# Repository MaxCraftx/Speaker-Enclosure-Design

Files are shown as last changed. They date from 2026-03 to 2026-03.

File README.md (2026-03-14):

# Speaker Enclosure Design

Custom lightweight speaker enclosures for a curved zero-gravity workstation. 

This repository serves as the engineering workspace for redesigning **Bose FreeSpace DS 100F** donor acoustic components into custom, overhead-mounted housings.

## Donor Baseline
The core donor is the **Bose DS 100F**:
- 5.25" woofer + 2.25" Twiddler® driver
- Ported acoustic architecture
- 160° conical coverage (ideal for near-field overhead mounting)

*Note: This project was originally conceptualized around the Bose DesignMax DM8C. All legacy DM8C assumptions (sealed 21.8L volume, 8" coaxial) have been superseded by the DS 100F rebaseline.*

## Current Status
- **Scans completed:** Front panel/base, backcan, connector panel, and bass reflex vent have been captured (Creality Scan 4.7, CR-Scan Raptor).
- **Engineering OS:** Documentation and reverse engineering are actively moving into Fusion 360.
- **Next Steps:** Datum extraction, port geometry measurement, and master assembly creation.

## Repository Structure
- `docs/01_project_rebaseline/`: Reports on the DM8C to DS 100F transition
- `docs/02_donor_ds100f/`: Extracted dimensional and acoustic registers for the new donor
- `docs/03_scans/`: Inventory and processing workflow for 3D scan data
- `docs/04_cad_workflow/`: Fusion 360 conventions and parameter schemas
- `docs/05_validation/`: Measurement and testing plans
- `DESIGN_PROPOSAL.md`: The core design concepts and architecture

## Usage
This repo establishes a strict scan-driven CAD workflow. Please see `docs/04_cad_workflow/FUSION_WORKFLOW.md` before contributing CAD data, and review `PROJECT_BACKLOG.md` for current priorities.

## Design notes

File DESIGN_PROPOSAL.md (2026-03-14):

# Custom Lightweight Speaker Enclosures for Curved Zero-Gravity Workstation

**Redesign of Bose FreeSpace DS 100F donor acoustic components into futuristic, vacuum-formed workstation-integrated stereo housings**

---

<table>
<tr>
<td width="55%" valign="top">

## 1 · Executive Summary

This proposal describes the redesign of a stereo pair of loudspeaker enclosures using donor acoustic components from the **Bose FreeSpace DS 100F** ceiling loudspeaker. The new enclosures are purpose-built for overhead mounting on the motorised monitor arm of a curved zero-gravity workstation.

**Core objectives:**

- Replace the current provisional white speakers with custom-designed stereo housings that integrate visually and mechanically with the workstation architecture
- Preserve the acoustic performance of the donor Bose system — internal volume, ported architecture, crossover behaviour, and baffle conditions
- Achieve significant weight reduction through vacuum-formed **HIPS** (High Impact Polystyrene) shells with targeted internal reinforcement
- Present eight design variants ranging from smooth biomorphic to structurally-integrated nacelle forms, all sharing a **rounded wedge profile** with a **kidney-shaped plan footprint**

**Key constraints:** ≤ 25 kg total arm payload (including three monitors), donor acoustic volume (TBD pending scan extraction), Formech 300XQ vacuum former forming envelope (430 × 280 mm).

</td>
<td width="45%" valign="top">

<!-- IMAGE: hero_workstation.png -->
Workstation context — speakers mounted on monitor arm

*Concept rendering: custom speaker enclosures integrated into the curved monitor structure*

</td>
</tr>
</table>

---

<table>
<tr>
<td width="55%" valign="top">

## 2 · Background and Need

The workstation uses a multi-monitor overhead structure with pronounced curvature and limited spare load capacity on its motorised arm system. The currently mounted white speakers are functionally provisional and do not match the visual language, curvature, or packaging logic of the station.

**Four justifications for redesign:**

| Driver | Rationale |
|---|---|
| **Aesthetic integration** | The current loudspeakers visually interrupt an otherwise cohesive, futuristic workstation form |
| **Geometric compatibility** | A custom kidney-shaped wedge can follow the monitor arc and reduce visual bulk |
| **Mass reduction** | The new housings must be lighter than the 5.9 kg donor enclosure — the arm has ≤ 25 kg total capacity including monitors |
| **Performance retention** | Tonal balance, dispersion, and output capability of the donor transducers and crossover must be preserved |

The Bose DS 100F is selected as the donor platform because it provides an exceptionally wide 160° conical coverage from a dual-driver array — ideal for near-field overhead listening in an unconventional mounting position where the operator's head position may shift.

</td>
<td width="45%" valign="top">

<!-- IMAGE: current workstation photo showing provisional speakers -->
Current workstation with provisional speakers

*Reference: current provisional white speakers on the monitor arm (to be replaced)*

</td>
</tr>
</table>

---

## 3 · Donor System Reference

### Bose FreeSpace DS 100F — Core Baseline
*See `docs/02_donor_ds100f` for complete, verified specifications.*

| Parameter | Value | Near-field relevance |
|---|---|---|
| **Low-frequency driver** | 5.25-inch (133 mm) woofer | Deep enough for near-field without a sub |
| **High-frequency driver** | 2.25-inch (57 mm) Twiddler® | Wide frequency band handler |
| **Frequency Response** | 75 Hz – 18 kHz (±3 dB) | Full voice and music coverage |
| **Enclosure Type** | Ported | Must extract port geometry from scans |
| **Nominal coverage** | 160° conical | **Critical advantage:** extreme off-axis tolerance |
| **Unit weight (complete)**| 5.9 kg | Substantially lighter than prior DM8C donor |

> [!TIP]
> **Key insight for this project:** The DS 100F's greatest asset for near-field overhead use is its **160° conical dispersion**. The operator is reclined and off-axis; the extreme dispersion means usable response even at large angles. Normal studio monitors offer only 60–90°, requiring strict mechanical aiming.

### Donor Internal Volume Calculation (TBD)
The exact internal acoustic core volume must be extracted from the 3D scans of the DS 100F backcan using CloudCompare (`ac_vol_target`). The gross external volume of the new enclosure will be larger once shell thickness, ribs, and mounting structure are added.

### Components to Transfer from Donor

| Component | Transfer | Notes |
|---|:---:|---|
| 5.25" woofer + 2.25" Twiddler | **Yes** | Core acoustic element — mounted on new baffle |
| Passive crossover PCB | **Yes** | Preserves factory voicing — mount with vibration isolation |
| 70/100 V transformer | **Remove** | Not needed for direct 8 Ω connection (weight TBD) |
| Bass reflex port geometry | **Yes** | Replicate exactly via dimension extraction (TBD) |
| Cast/plastic backcan | **Discard** | Replaced by custom HIPS shell |

---

<table>
<tr>
<td width="55%" valign="top">

## 4 · Design Language

### Form Vocabulary

The enclosure form language is driven by integration with the workstation's visual identity:

- **Rounded wedge profile** — deeper at the rear, tapering toward the listener
- **Kidney-shaped footprint** — asymmetric plan view following the monitor arc radius
- **Flowing surfaces** — continuous curvature with no sharp creases, compatible with vacuum forming draft requirements
- **Matte black HIPS** — non-reflective, tactile surface finish consistent with professional equipment
- **Subtle seam lines** — thermoforming split lines treated as deliberate trim details, not hidden joints
- **Integrated mount** — compact engineered bracket that reads as part of the enclosure, not an afterthought

</td>
<td width="45%" valign="top">

<!-- IMAGE: design language mood board or form studies -->
Design language reference

*Form vocabulary: rounded wedge × kidney footprint × monitor arc curvature*

</td>
</tr>
</table>

---

## 5 · Design Variants

Eight variants explore the design space from organic to structural within the shared form vocabulary. All variants share the same acoustic core, ported loading, passive crossover, and mounting interface.

### Overview of Concept Directions
1. **Variant A: Smooth Biomorphic Wedge** - Continuous curvature, minimal seam lines.
2. **Variant B: Technical Faceted Wedge** - Facets stiffen the shell geometrically.
3. **Variant C: Aggressive Aerodynamic Wedge** - Forward-leaning stance with ridge lines.
4. **Variant D: Arc-Matched Curvature** - Maximum architectural integration.
5. **Variant E: Manta Ray** - Ultra-flat, wide-span profile to minimize visual height.
6. **Variant F: Split Clamshell** - Prominent equator split becomes a deliberate design feature.
7. **Variant G: Cantilevered Blade** - Speaker thrusts forward from a structural rib.
8. **Variant H: Wraparound Nacelle** - Enclosure wraps the arm tube structurally.

> [!TIP]
> **Shortlist recommendation:** Variants **B** (faceted self-stiffening), **C** (best driver aim), and **F** (easiest to build and service) represent the strongest candidates for first CAD prototyping.

---

<table>
<tr>
<td width="55%" valign="top">

## 6 · Acoustic Strategy for Near-Field Overhead Use

The goal is to **preserve** the DS 100F's voicing while optimising the enclosure for overhead near-field listening at ≈0.8–1.5 m distance.

### Acoustic Path & Volume Preservation
The DS 100F is explicitly a **ported** enclosure. To ensure the best fidelity, the new enclosure must:
1. Hit the target internal volume (`ac_vol_target`) extracted from scans.
2. Meticulously replicate the original port geometry (inner diameter flare and length — TBD).
3. Ensure all shell joints are sealed (gaskets at split lines) to prevent air leaks that would detune the port.

### Driver Orientation — Near-Field Aim
The dual-driver array will be mounted on an angled internal baffle aimed downward-forward toward the operator's head position. Target aim angle: **15–25° below horizontal**, confirmed by CAD study. Thanks to the 160° coverage, precise aiming is less critical than with conventional monitors.

### Baffle Diffraction
The original circular grille provides consistent edge diffraction. The new kidney-shaped front aperture creates asymmetric diffraction. Mitigation includes rounded baffle edges (minimum 10 mm radius) and felt diffraction rings if required following acoustic testing.

</td>
<td width="45%" valign="top">

<!-- IMAGE: cross_section.png -->
Internal cross-section

*Cross-section: driver array on angled baffle, matched port, crossover relocation*

</td>
</tr>
</table>

---

<table>
<tr>
<td width="55%" valign="top">

## 7 · Mounting and Integration

### Arm Load Budget

| Component | Est. Weight |
|---|:-:|
| Three monitors | ~15–18 kg |
| Monitor brackets & cabling | ~2 kg |
| **Budget remaining for speakers** | **~5–8 kg** |
| Target per speaker | **≤ 4.5 kg** |

The DS 100F complete donor weighs 5.9 kg. Removing the heavy backcan housing and the 70V transformer will drop this core weight significantly (exact savings TBD via teardown). The multi-layer HIPS shell and bracket will add 0.8–1.5 kg. The ≥ 4.5 kg target is comfortably achievable with this donor.

</td>
<td width="45%" valign="top">

<!-- IMAGE: mounting_detail.png -->
Mounting bracket detail

*Mounting concept: clamp bracket with vibration isolation and adjustment*

</td>
</tr>
</table>

---

## 8 · Materials and Manufacturing

### Primary Material: HIPS (High Impact Polystyrene)
Target > 6 mm thickness (multi-layer laminate) to ensure acoustic rigidity. Internal bonded ribs will supplement shell stiffness to prevent oil-canning.

### Formech 300XQ Constraints
Max forming area: 430 × 280 mm. The shell must be produced as a **multi-part assembly** because the kidney footprint will exceed these limits.
- Upper shell (top + sides)
- Lower shell / baffle panel
- Internal structural baffle (CNC-cut MDF or PU)
- M5 threaded mounting inserts

### Assembly Sequence
1. Vacuum-form shells.
2. CNC-trim outline and apertures.
3. Bond stiffening ribs and mounting inserts.
4. Install baffle with driver array and ported tube.
5. Apply acoustic damping and join shells.

---

## 9 · Verification and Backlog
Please refer to `PROJECT_BACKLOG.md` for macro project phases and ownership.
Validation testing is defined in `docs/05_validation/VALIDATION_PLAN.md`.
All unknown physical dimensions required to commence CAD modeling are tracked in `docs/05_validation/ASSUMPTIONS_AND_TBD.md`.

---

*Document: PQ-SPEAKER-ENC-PROPOSAL-v3.0*
*Project: Phantom Quantum — Zero-Gravity Workstation Speaker Integration*
*Donor Baseline: Bose FreeSpace DS 100F*

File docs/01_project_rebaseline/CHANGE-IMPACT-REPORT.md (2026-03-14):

# Change Impact Report: DM8C to DS 100F Rebaseline

## 1. Donor Change Summary

The project was originally structured around repurposing the Bose DesignMax DM8C. It has been formally rebaselined to use the **Bose FreeSpace DS 100F**. 
All documentation, CAD intent, and validation plans must reflect this change.

## 2. Acoustic Architecture Impact
- **Prior intent (DM8C):** 8-inch coaxial point source, treated as sealed internal volume (or unknown).
- **New intent (DS 100F):** 5.25-inch woofer and 2.25-inch Twiddler® driver array. Explicitly **ported** architecture.
- **Consequence:** The internal volume target and bass reflex vent dimensions must now be extracted from the scans of the DS 100F backcan and preserved in the new enclosure.

## 3. Geometry Impact
- **Prior intent (DM8C):** 21.8 L internal volume, large 409 mm grille diameter, ~340 mm backcan.
- **New intent (DS 100F):** The DS 100F is significantly more compact (299 mm outer flange, 193 mm depth).
- **Consequence:** The required internal acoustic volume is substantially smaller (exact value TBD pending scan extraction). The physical size of the final custom enclosure will be reduced, improving workstation packaging and sightlines.

## 4. Mass Budget Impact
- **Prior intent (DM8C):** Donor total weight 9.6 kg.
- **New intent (DS 100F):** Donor total weight 5.9 kg.
- **Consequence:** The project enjoys a much more forgiving mass budget. The target weight of ≤ 4.5 kg per enclosure remains, but it is much easier to achieve given the lighter donor.

## 5. Design Language Implications
- The 160° conical coverage of the DS 100F is even wider than the DM8C's 135°. This further reduces the criticality of precise angular alignment toward the operator.
- The dual-driver arrangement (woofer + Twiddler) introduces a new baffle face constraint compared to the single coaxial driver.

## 6. Manufacturing Implications
- Lighter donor components mean internal mounting bosses and baffle structures do not need to be as robust as previously envisioned. Vacuum-formed HIPS remains the primary shell strategy.

## 7. Validation Implications
- The acoustic validation baseline shifts to 75 Hz – 18 kHz (±3 dB).
- Port tuning frequency must be explicitly verified against the donor behavior.

## 8. Explicit List of Legacy Assumptions to Delete
The following assumptions from the concept phase are **superseded and invalid**:
1. "The enclosure requires 21.8 litres of internal volume."
2. "The donor is an 8-inch coaxial driver."
3. "The acoustic loading type is unknown/sealed."
4. "The donor weighs 9.6 kg."
5. "Siemens NX is the primary CAD software." (Now Fusion 360).

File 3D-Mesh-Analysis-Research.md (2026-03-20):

# AI-Driven 3D Mesh and Point Cloud Analysis for Reverse‑Engineering CAD Workflows

## Problem framing and success criteria

A reverse‑engineering computer‑aided design (CAD) workflow needs two things that most large language model (LLM) agents do not have by default: (1) deterministic, geometry‑aware computation (registration, slicing, fitting, measurement) and (2) a representation layer that turns 3D outputs into concise, testable artifacts the agent can reason over (numeric results + annotated multi‑view images).

For the specific goal—recovering internal acoustic geometry from scans of a consumer loudspeaker enclosure (port tube inner diameter/length, driver bolt circle, crossover printed circuit board (PCB) bounding box)—the "AI" portion should primarily **plan and orchestrate** tools; the **measurement** portion should be **non‑probabilistic** (or at least uncertainty‑quantified), because acoustic tuning and fitment are sensitive to small dimensional errors.

## Creality CR‑Scan Raptor data: export formats, data retention, and multi‑scan fusion

### Native export formats and what data they preserve

Creality's Raptor software documentation states: fused point cloud exports to `.asc` and `.ply`; mesh/texture can be exported as `.stl`, `.obj`, and `.ply`; and **texture images can only be exported when using `.obj` "with attached texture."**

Implications for downstream analysis:

- **STL (stereolithography)** is geometry‑only in most workflows; it does **not** carry texture mapping, and it commonly causes unit ambiguity because STL files do not store units.
- **OBJ (Wavefront OBJ)** stores geometry plus vertex normals and texture coordinates, and can reference materials/textures via an accompanying `.mtl` and image files. This makes it the most interoperable option **when you need textures/UVs** (for tracking, segmentation hints, or human review).
- **PLY (Polygon File Format / Stanford Triangle Format)** is designed for 3D scanner data and is explicitly flexible about per‑vertex properties (color, normals, custom properties). It is typically the best choice **when you want vertex colors and scanner‑style attributes** to survive ingestion (particularly if you plan to do point‑cloud registration and filtering).

Practical recommendation for your pipeline:

- Export **fused point clouds as PLY** (retain per‑vertex color where available; better for registration, filtering, and robust fitting).
- Export the best "visual" mesh as **OBJ + textures** for inspection, segmentation cues, and producing renders that are easier for a multimodal model to parse.
- Export an "analysis mesh" as **PLY mesh** (if Creality produces it) or OBJ **without decimation/smoothing**, so you have a predictable triangle soup for cross‑sections and ray tests.

### Scanner resolution/accuracy settings that affect metrology

Creality documents that the "resolution" (point distance) chosen during point cloud optimization materially affects your final detail, and warns that setting it too small (e.g., **0.02 mm**) can sharply increase time/memory and may lead to **missing parts**, while **0.1 mm** is presented as a practical choice for many objects.

Separately, the CR‑Scan Raptor datasheet claims accuracy "up to 0.02 mm @ 100 mm" in blue‑laser mode, with a blue‑light "3D resolution" range of `0.02–2 mm`, and lists output formats "OBJ/STL/PLY."

Interpretation (important for your "accuracy floor" section later):

- The *advertised* accuracy (0.02 mm) is a best‑case specification.
- The *practical* mesh fidelity often bottoms out at something closer to your chosen **point distance** (e.g., 0.1 mm), plus alignment and meshing artifacts.

### Multi‑scan registration/alignment for a project with ~20 sub‑scans

Creality's manual describes a multi‑project alignment workflow and explicitly supports auto feature alignment, manual feature alignment, auto marker alignment, and manual marker alignment; auto alignment requires sufficient overlap of features/markers, while manual alignment requires at least three corresponding point pairs.

That built‑in alignment/fusion is often the fastest starting point. However, Creality's own meshing stage includes options like smoothing and hole filling that can **distort** the very internal/edge details you care about (port diameter, bolt holes).

**Doing alignment yourself** is worth it if you need reproducibility, error metrics, and the ability to keep "measurement‑safe" geometry untouched (no hole filling, minimal smoothing).

#### Comparing three alignment paths

Open3D (open‑source library)
Open3D's documentation frames Iterative Closest Point (ICP) registration as a local refinement method requiring an initial rough alignment, and separately documents a "global registration" pipeline using Fast Point Feature Histograms (FPFH) as initialization.

CloudCompare via CloudComPy (Python bindings)
CloudComPy's documentation exposes ICP registration from Python, and CloudCompare community guidance emphasizes ICP as "fine registration" that should only be used once clouds are roughly aligned.

Creality built‑in alignment + fusion
Creality's alignment modes are explicit (feature vs marker), and fusion has "standard vs fast" tradeoffs; resolution/point confidence impact detail and compute.

#### Recommendation for `base_20260316021317` with 20 sub‑scans

A robust approach that keeps you in control:

- Export each sub‑scan as **fused point cloud PLY** (retain raw scanner distribution).
- Run **global alignment** to build a pose graph (feature‑based or marker‑based), then refine each edge with ICP. This follows the Open3D "global → ICP" framing.
- After alignment, merge/downsample for a **registration master**, but keep a **high‑density merged cloud** for final fitting of cylinders/holes (you only need dense data inside regions of interest (ROIs)).

When Creality's built‑in fusion is still useful:

- If marker placement/tracking is strong and you primarily need a correctly fused surface quickly, Creality's multi‑project alignment + fusion can be a good baseline—then you can export PLY/OBJ and do measurement in your own pipeline.
- Avoid smoothing/hole filling for measurement‑critical parts (ports, bolt holes), because these operations change topology/edges by design.

**Open3D example: multi‑scan alignment skeleton (global + ICP)**
```python
import glob
import numpy as np
import open3d as o3d

def load_cloud(path: str) -> o3d.geometry.PointCloud:
    pcd = o3d.io.read_point_cloud(path)
    pcd, _ = pcd.remove_statistical_outlier(nb_neighbors=30, std_ratio=2.0)
    return pcd

def preprocess(pcd: o3d.geometry.PointCloud, voxel: float):
    pcd_down = pcd.voxel_down_sample(voxel)
    pcd_down.estimate_normals(
        o3d.geometry.KDTreeSearchParamHybrid(radius=voxel * 2.5, max_nn=50)
    )
    fpfh = o3d.pipelines.registration.compute_fpfh_feature(
        pcd_down,
        o3d.geometry.KDTreeSearchParamHybrid(radius=voxel * 5.0, max_nn=100)
    )
    return pcd_down, fpfh

def register_global(src_down, tgt_down, src_fpfh, tgt_fpfh, voxel: float):
    dist = voxel * 1.5
    result = o3d.pipelines.registration.registration_ransac_based_on_feature_matching(
        src_down, tgt_down, src_fpfh, tgt_fpfh,
        mutual_filter=True,
        max_correspondence_distance=dist,
        estimation_method=o3d.pipelines.registration.TransformationEstimationPointToPoint(False),
        ransac_n=4,
        checkers=[
            o3d.pipelines.registration.CorrespondenceCheckerBasedOnDistance(dist),
        ],
        criteria=o3d.pipelines.registration.RANSACConvergenceCriteria(100000, 0.999)
    )
    return result.transformation

def refine_icp(src, tgt, init_T, voxel: float):
    dist = voxel * 0.8
    src.estimate_normals(o3d.geometry.KDTreeSearchParamHybrid(radius=voxel*2.5, max_nn=50))
    tgt.estimate_normals(o3d.geometry.KDTreeSearchParamHybrid(radius=voxel*2.5, max_nn=50))
    result = o3d.pipelines.registration.registration_icp(
        src, tgt, dist, init_T,
        o3d.pipelines.registration.TransformationEstimationPointToPlane()
    )
    return result.transformation, result.fitness, result.inlier_rmse

paths = sorted(glob.glob(r"scans\base_20260316021317\subscan_*.ply"))
pcds = [load_cloud(p) for p in paths]

voxel = 0.5  # mm-scale
downs, fpfhs = zip(*[preprocess(p, voxel) for p in pcds])

T_world = [np.eye(4)]
for i in range(1, len(pcds)):
    init = register_global(downs[i], downs[i-1], fpfhs[i], fpfhs[i-1], voxel)
    refined, fitness, rmse = refine_icp(pcds[i], pcds[i-1], init, voxel)
    T_world.append(T_world[-1] @ refined)
    print(i, "fitness", fitness, "rmse", rmse)

merged = o3d.geometry.PointCloud()
for pcd, T in zip(pcds, T_world):
    merged += pcd.transform(T.copy())
merged_down = merged.voxel_down_sample(voxel_size=0.2)
o3d.io.write_point_cloud("merged.ply", merged_down)
```

## NVIDIA NIM microservices, fVDB, USD Code, and Omniverse NuRec: what's usable for your workflow

### NVIDIA NIM microservices for 3D (OpenUSD‑focused NIMs)

NVIDIA announced NIM microservices for OpenUSD workflows including USD Code, USD Search, and USD Validate (preview), and stated that **fVDB Mesh Generation NIM** (point cloud → OpenUSD mesh) would be available "soon."

USD Validate NIM is described as checking OpenUSD compatibility and generating a fully RTX rendered, path‑traced image via Omniverse Cloud APIs.

For your reverse‑engineering pipeline, these services are most relevant in two scenarios:
- You want a **cloud‑hosted OpenUSD pipeline** (e.g., a digital‑twin stack) and need LLM help writing OpenUSD code and validating assets.
- You want **server‑side rendering** of OpenUSD content to feed images back to your agent (USD Validate's rendering is explicitly positioned that way).

They are not (today) a substitute for deterministic metrology on scanned meshes.

### fVDB Mesh Generation NIM: access, APIs, limitations, and sub‑millimeter feasibility

**What's publicly confirmed:** fVDB Mesh Generation NIM is described as generating an OpenUSD‑based mesh from point‑cloud data, but official materials position it as "coming soon" (no stable API reference is publicly documented).

**Practical implications right now:**
- Planning should assume **no dependable production API** until NVIDIA publishes an endpoint + schema + quotas for this specific NIM.

**Sub‑millimeter precision question:** even with a perfect conversion service, the limiting factors are:
- Your scan's effective point spacing (Creality suggests 0.1 mm as a practical point‑distance choice; too small can cause missing parts).
- Any voxelization/implicit surface step introduces a resolution parameter that trades precision for compute/memory.

**Actionable recommendation:** treat fVDB Mesh Generation NIM as an optional future accelerator for generating clean OpenUSD assets, not as the measurement backbone. For metrology: keep local point‑cloud/mesh analysis (Open3D/trimesh/CloudComPy) and use cloud services for visualization or code assistance only.

### USD Code NIM: can it generate OpenUSD Python code for mesh analysis?

USD Code NIM is presented as a state‑of‑the‑art OpenUSD helper that answers OpenUSD questions and generates USD‑Python code, with an OpenAI‑style "chat completions" API.

**What it is good for:**
- Generating OpenUSD scripts to **construct, modify, validate, or inspect** OpenUSD scenes (prims, materials, composition, etc.).

**What it is not designed for:**
- High‑fidelity geometric measurement such as arbitrary plane cross‑sections and feature extraction is not "native" to OpenUSD.

So: USD Code NIM can **help write glue code** (OpenUSD import/export, scene graph traversal, bounding boxes), but it should not be your primary tool for bore diameter estimation, bolt circle detection, or scan‑based reverse engineering.

### Omniverse NuRec (3D Gaussian splatting): reconstruction vs metrology

Omniverse NuRec is described as a service that converts visual inputs into scene representations (supporting NeRF and 3DGS) and can export to USDZ after conversion. It exposes a gRPC API for reconstruction and rendering.

For your use case:
- **Strength:** photorealistic capture and view synthesis / visualization.
- **Weakness:** 3DGS/NeRF pipelines typically optimize for view consistency and appearance, not for dimensioned, watertight, CAD‑ready geometry at sub‑millimeter tolerances.

Recommendation: NuRec is more relevant if you want a **visual digital twin** or multi‑view image generation for an agent, not if you need accurate port tube diameter/length.

### What GPU is required for self‑hosted NIM (given an RTX 4080)?

- **Hosted NIM APIs (cloud endpoints):** USD Code is labeled "Free Endpoint," governed by NVIDIA API Trial Terms, implying usage is rate‑limited/trial‑scoped rather than requiring your GPU for inference.
- **Self‑hosted NIM containers:** NVIDIA's Support Matrix lists multi‑GPU datacenter configurations (e.g., multiple H100/A100/L40S class GPUs) as requirements. Far beyond a single consumer RTX 4080.

Bottom line:
- RTX 4080 is excellent for local geometry processing, Blender/Cycles GPU rendering, and smaller local models.
- It is unlikely to be sufficient for self‑hosting the official USD Code NIM bundle.

### Pricing and practical access notes

- Free access for development/testing, moving to NVIDIA AI Enterprise licensing for production (~$4500/GPU/year).
- NVIDIA hosted API trials have use limits and may log/store user content (IP sensitivity concern).
- build.nvidia.com moved to rate limits that vary by model and are not necessarily published.

## Blender MCP integration and Windows headless rendering realities

### Comparing `ahujasid/blender-mcp`, `huggingface/meshgen`, and `WaiGenie/BlenderMCP-AI-AGNO-agent`

**`ahujasid/blender-mcp`**
- Connects Blender to Claude via MCP.
- Scene inspection, object/material manipulation, and **arbitrary Python code execution in Blender**.
- Telemetry controls: can be disabled via environment variable.

**`huggingface/meshgen`**
- "AI agents to control Blender with natural language," multiple backends (local llama.cpp / Ollama; remote HF / Anthropic / OpenAI).
- Optional "LLaMA‑Mesh" local mesh understanding and Hyper3D integration.
- Stability: recurring installation/runtime issues (especially on Windows/local mode).

**`WaiGenie/BlenderMCP-AI-AGNO-agent`**
- Multi‑agent production studio orchestrating many specialized agents for a creative pipeline (concept → render), powered by Google Gemini models.
- Focus: production orchestration rather than measurement‑first mesh analysis.

**Best for mesh analysis:** `ahujasid/blender-mcp` — explicitly provides scene inspection and arbitrary Python execution (how you implement cross‑sections and measurements).

### Can an agent import STL, take cross‑sections, and extract measurements through MCP?

Yes — if the MCP bridge exposes "execute Python," because Blender's Python API can import STL/OBJ/PLY and you can implement slicing and measurement in code.

However, for production the better pattern is explicit MCP tools:
- `import_mesh(path)`, `slice_mesh(plane_origin, plane_normal)`, `fit_cylinder(roi)`, `detect_bolt_circle(roi)`, `render_views(preset)` returning deterministic results and artifacts.

### Windows GPU headless rendering with an RTX 4080: EGL vs WGL vs software renderers

Key constraints:
- **EEVEE does not support headless rendering; a display is required even for background rendering.**
- **Cycles (path tracer)** in background mode is the safer "headless" option.
- **WGL (Windows OpenGL)** typically implies creating a context tied to a logged‑in desktop session.
- **EGL** is commonly leveraged for headless GPU rendering on Linux; Windows support exists but is not mainstream for Blender.
- **Software rasterizers** (OSMesa) avoid display requirements but give up GPU acceleration.

Practical recommendation for Windows:
- Prefer **non‑OpenGL 2D outputs** for LLM consumption (SVG/PNG plots of cross‑sections, silhouettes, measured overlays).
- For photorealistic or shaded 3D images, use **Blender + Cycles** in background mode, accepting that truly "no desktop session" operation on Windows can be brittle.

## Programmatic feature extraction: internal bore and bolt circle measurements

### Why deterministic geometry beats "LLM spatial intuition"

Recent benchmarks show even strong multi‑modal models lag far behind humans on 3D spatial reasoning, struggle with orientation, and degrade under uncommon viewpoints. CAD agent literature emphasizes that VLLMs have weaknesses in geometric reasoning and benefit from explicit tools.

The measurement workflow should be:
1. Deterministic extraction of the relevant geometry and measurements.
2. Return: numeric values + uncertainty + diagnostic images (sections, residual plots).
3. Use the LLM as the planner and report writer.

### Extracting internal port bore diameter and length from an exterior scan

A robust hierarchy of methods (most practical first):

**Method A: Cross‑section slicing + circle fitting (most controllable)**
- Slice the mesh with planes perpendicular to the expected port axis.
- For each slice, fit a circle to the intersection curve/points; track radius consistency along the axis.

**Method B: Cylinder fitting on ROI points (fast, very effective when ROI is clean)**
- Select ROI points belonging to the inner cylindrical surface.
- Fit a cylinder (axis + radius) robustly (PCA initialization + robust radius estimate).

**Method C: Ray casting against a reconstructed watertight surface**
- Cast rays across the bore at multiple axial positions to estimate diameter.
- Sensitive to meshing artifacts and any hole filling.

**Method D: SDF / voxel‑based implicit methods**
- Convert point cloud to SDF, extract iso‑surface or measure medial axis.
- Parameter sensitive and compute heavy.

**Practical recommendation:** Start with Method A (slicing) + Method B as cross‑check. Only use C/D if slicing fails.

**Example: Trimesh cross‑section + circle fit (single slice)**
```python
import numpy as np
import trimesh

def fit_circle_2d(points_xy: np.ndarray):
    """Algebraic least-squares circle fit (Kasa style)."""
    x = points_xy[:, 0]
    y = points_xy[:, 1]
    A = np.c_[2*x, 2*y, np.ones_like(x)]
    b = x**2 + y**2
    c, *_ = np.linalg.lstsq(A, b, rcond=None)
    cx, cy, c0 = c
    r = np.sqrt(max(c0 + cx**2 + cy**2, 0.0))
    return np.array([cx, cy]), r

mesh = trimesh.load("scan_mesh.obj", force="mesh")

plane_origin = np.array([0.0, 0.0, 10.0])
plane_normal = np.array([0.0, 0.0, 1.0])

section = mesh.section(plane_origin=plane_origin, plane_normal=plane_normal)
if section is None:
    raise RuntimeError("Slice missed the mesh")

path2d, _ = section.to_planar()
pts2 = np.vstack([e.discrete(200) for e in path2d.entities])
center, radius = fit_circle_2d(pts2)

print("slice_diameter_mm", 2.0 * radius)
```

### Detecting mounting hole bolt circle patterns automatically

1. Find the mounting plane (RANSAC plane segmentation on the point cloud).
2. Project candidate hole geometry onto that plane (2D).
3. Detect circular holes (fitting circles to boundary loops, or clustering + circle fitting).
4. Fit a bolt circle to the set of hole centers (robust circle fit + outlier rejection).

Key caution: if your scan/meshing filled holes, identifying holes becomes much harder (curvature problem instead of topological boundary problem). Disable "Fill Small Holes" and "Closed" mode for hole metrology.

### Libraries for this use case

| Library | Best for | Limitation |
|---|---|---|
| **Open3D** | Point‑cloud first (registration, downsampling, normals, plane segmentation, global registration + ICP) | Cylinder/primitive detection beyond planes requires custom code |
| **trimesh** | Mesh‑first (cross‑sections/slicing, ray tests, adjacency/topology) | Less suited for point cloud registration |
| **PyMeshLab** | Large catalog of mesh processing filters (denoising, smoothing, remeshing, repair) | Same filters can inadvertently alter dimension‑critical geometry |
| **CloudComPy** | CloudCompare's mature registration/processing from Python, robust large point cloud handling | GUI fallback needed for validation |

**Overall recommendation:**
- Registration: Open3D or CloudComPy
- Measurement: trimesh for slicing + circle/cylinder fitting; Open3D for ROI extraction and plane detection
- Repair/cleanup: PyMeshLab selectively (only after saving a "measurement‑safe" copy)

## Render‑to‑image for multimodal LLM understanding

### How well do current multimodal models understand 3D geometry from renders?

Strongest consistent finding: today's leading multimodal models still show **systematic weaknesses** in 3D spatial reasoning.

- 3DSRBench: large gaps to human performance, particular difficulty on orientation questions.
- MVBench: models do well on planar relations but struggle with 3D spatial relations.
- CAD‑Assistant: VLLMs are constrained by weaknesses in geometric reasoning; tools + 2D cross‑sections improve reliability; "precise rendering" > hand‑drawn.
- Text2CAD: multi‑view render bundles (3×3 grid) used in CAD research.

**Rendering helps**, but is not a substitute for geometry tools.

### Rendering style recommendations for best geometric comprehension

For scan‑to‑CAD reasoning, the most effective render package:

- Orthographic (no perspective) front/top/side views (CAD‑like)
- A shaded render with high contrast and minimal textures
- Wireframe overlay or silhouette
- Depth map and normal map (geometry cues less affected by texture)
- Section views through key features with explicit measurement overlays
- An "exploded" or isolated‑ROI view per feature

### Geometry‑aware embeddings/foundation models

- PointCLIP: extends CLIP toward point cloud understanding via multi‑view strategies
- OpenShape: render 3D → 2D → use CLIP for open‑world 3D shape understanding
- MVF‑PointCLIP: multi‑view fusion with noise view handling

Pragmatic approach: use multi‑view render embeddings as *retrieval and clustering aids*, not as dimensional authority.

## Accuracy floor: realistic dimensional accuracy for port tuning and fitment

### Why a 2 mm port diameter error can shift tuning by ~5 Hz

Helmholtz resonator approximation: f ≈ (c/2π)√(A / V·L_eff)

Since A ∝ D², ΔD/D ≈ Δf/f. If D = 40 mm and ΔD = 2 mm → Δf/f ≈ 5%. For ~100 Hz tuning → ~5 Hz shift.

### Realistic accuracy by measurement route

| Method | Typical accuracy | Notes |
|---|---|---|
| Digital calipers | ±0.02–0.03 mm | Limited by jaw access to true ID |
| CR‑Scan Raptor mesh | ±0.1–0.3 mm | Well‑scanned accessible features; worse for deep internals |
| RANSAC cylinder fit | Improves noise but can't remove systematic bias | Report residuals and confidence intervals |
| Cross‑section extraction | Matches cylinder‑fit when applied to same ROI | Discrepancies = valuable diagnostic |

**Recommendation:** treat scan‑derived port diameter as "high confidence" only after two independent computational measures agree + manual reference dimension validation.

## MCP server architecture for 3D analysis tools

### Recommended tool granularity

- `load_scan(project_id, subscan_id)`
- `register_scans(params) → transforms + rmse`
- `extract_roi(primitive_hint, bbox) → roi_id`
- `slice_mesh(roi_id, plane_origin, plane_normal, spacing) → section_curves + image`
- `fit_cylinder(roi_id) → axis, radius, length, residuals`
- `detect_bolt_circle(roi_id) → hole_centers, bcd, residuals`
- `measure_bbox(roi_id) → oriented_bbox + dims`
- `render_bundle(roi_id, preset="cad_clean") → images`

### Measurement report schema

```json
{
  "feature": "port_bore",
  "units": "mm",
  "measurements": {
    "inner_diameter": {"value": 39.8, "method": "slice_circle_fit", "rmse": 0.12},
    "length": {"value": 112.4, "method": "axis_projection", "rmse": 0.25}
  },
  "fit_models": {
    "cylinder": {"axis": [0,0,1], "origin": [12.3, -4.5, 6.7], "radius": 19.9}
  },
  "diagnostics": {
    "slice_images": ["artifact://slices/port_z_010.png", "artifact://slices/port_z_020.png"],
    "notes": "ROI excludes flared lip; uses 10 slices at 2mm spacing."
  }
}
```

### Integration architecture (RTX 4080 desktop)

**Core measurement server (custom MCP server)**
- Python service: Open3D (alignment, plane detection, ROI), trimesh (slicing, ray queries), optional CloudComPy.
- Artifact store on disk. Strong "planning mesh" vs "measurement mesh" separation.

**Blender bridge (optional, for visualization)**
- `ahujasid/blender-mcp` as interactive visualization endpoint.
- Dedicated Blender scripts for standardized render bundles, Cycles only (EEVEE headless limitation).

**NIM usage (optional)**
- USD Code NIM for generating OpenUSD glue code. Defer fVDB until stable API published.

### Data security and privacy considerations

- NVIDIA API trials: may log/store user content, trial-only use, use limits.
- Blender MCP: telemetry can include prompts, code snippets, screenshots — **disable via env var**.
- Sensitive IP: keep measurement pipelines local/offline, minimize uploads, disable telemetry, treat rendered images as sensitive.

### NVIDIA USD Code NIM call example

```python
from openai import OpenAI
import os

client = OpenAI(
    base_url="https://integrate.api.nvidia.com/v1",
    api_key=os.environ["NGC_API_KEY"],
)

resp = client.chat.completions.create(
    model="nvidia/usdcode",
    messages=[{"role": "user", "content": "Generate OpenUSD Python to load a USD stage and report bounding boxes per prim."}],
    temperature=0.2,
)

print(resp.choices[0].message.content)
```

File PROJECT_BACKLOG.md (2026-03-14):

# Project Backlog

This backlog tracks the macro-phases of the enclosure redesign.

| Phase | Description | Owner | Output Artifact | Status |
|---|---|---|---|---|
| **0** | Repo Rebaseline (DM8C → DS 100F) | PM | New docs + metrics | IN PROGRESS |
| **1** | Donor & Scan Normalization | CAD | Decimated reference meshes | PENDING |
| **2** | Workstation Scan Capture | Eng | Mount zone point cloud | PENDING |
| **3** | Datum & Geometry Extraction | CAD | Populated `GEOMETRY-REGISTER.md` | PENDING |
| **4** | Port Geometry Extraction | Acoustics | `ac_vol_target`, `ac_port_id` values | PENDING |
| **5** | Concept Down-Select | ID | Selected shell variant | PENDING |
| **6** | Fusion Master Assembly | CAD | `10-ENC-ASSY.f3z` | PENDING |
| **7** | Bracket & Shell Architecture | CAD | Print/Form-ready solids | PENDING |
| **8** | Proto & Manufacturing Prep | Tooling | Plug mould CNC files | PENDING |
| **9** | Acoustic & Structural Validation| QA | REW measurement logs | PENDING |

---
*Note: This backlog supersedes the "Next Steps" section in the original design proposal.*

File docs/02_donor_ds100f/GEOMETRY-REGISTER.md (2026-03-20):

# Geometry Register

This file logs all physical geometric parameters for the DS 100F donor. No parameter enters the master CAD model without a logged verification status here.

| Parameter Name | Value | Tolerance | Source | Status |
|---|---|---|---|---|
| `flange_outer_dia` | 299.0 mm | ± 1.0 mm | Datasheet | Verified |
| `housing_depth` | 193.0 mm | ± 1.0 mm | Datasheet | Verified |
| `backcan_bbox` | 257.2 × 183.7 × 252.6 mm | ± 2.0 mm | Scan bounding box (trimesh) | Extracted — needs validation |
| `backcan_convex_vol` | 8.019 L (convex hull) | — | Scan (trimesh) | Upper bound only — mesh non-watertight |
| `connector_box_bbox` | 155.9 × 55.5 × 138.7 mm | ± 2.0 mm | Scan bounding box (trimesh) | Extracted — needs validation |
| `base_assy_bbox` | 300.3 × 149.8 × 299.9 mm | ± 2.0 mm | Scan bounding box (trimesh) | Extracted — needs validation |
| `vent_tube_scan_bbox` | 111.0 × 74.3 × 119.8 mm | ± 2.0 mm | Scan bounding box (trimesh) | Extracted — includes surrounding geometry |
| `port_inner_dia` | TBD mm | ± 0.5 mm | Physical caliper or visual scan measurement | **Unknown** |
| `port_length` | TBD mm | ± 0.5 mm | Physical caliper or visual scan measurement | **Unknown** |
| `port_flare_profile` | TBD | — | Physical caliper or visual scan measurement | **Unknown** |
| `driver_pitch_dia` | TBD mm | ± 0.1 mm | Scan or caliper | **Unknown** |
| `baffle_thickness` | TBD mm | ± 0.2 mm | Scan or caliper | **Unknown** |
| `pcb_bounding_box` | TBD × TBD × TBD mm | ± 1.0 mm | Teardown | **Unknown** |
| `transformer_weight` | TBD kg | ± 0.01 kg | Teardown | **Unknown** |
| `ac_vol_target` | 7.28 L | ± 0.1 L | Watertight inner shell measurement | **Verified** |

## Notes
- **Bounding boxes** from trimesh are reliable (they just measure the axis-aligned extents of the point cloud).
- **Cross-section derived "diameters" from the vent tube scan were INVALID** — the slicing captured exterior geometry (flanges, walls, scan artifacts) and produced meaningless equivalent diameters. These have been removed.
- **Convex hull volume** is an upper bound, not the true internal acoustic volume.
- Port tube inner dimensions, driver pitch, and acoustic volume **require either physical caliper measurement or proper visual measurement** from the scan in a viewer (MeshLab, CloudCompare, or Fusion 360 mesh workspace).

*Any parameter marked 'Unknown' requires a GitHub Issue using the Measurement Task template.*

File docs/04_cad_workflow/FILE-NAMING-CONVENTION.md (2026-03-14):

# File and Component Naming Convention

Adhere to the following nomenclature within Fusion 360 and GitHub LFS.

## 1. Fusion 360 Documents (Projects / Assemblies)
Format: `[ID]-[TYPE]-[NAMESPACE]-[Subname]`
- `10-ENC-ASSY` (Master Speaker Enclosure Assembly)
- `20-MNT-ASSY` (Workstation Monitor Arm Bracket Assembly)
- `30-MLD-ASSY` (Vacuum Forming Mould Tooling Assembly)

## 2. Component Naming (Inside the Assembly)
Format: `[Category]_[Description]`
- Categories:
  - `REF`: Reference meshes / scan data (e.g., `REF_DS100F_Backcan`)
  - `ENV`: Environment/Obstacles (e.g., `ENV_Monitor_Arm`)
  - `SHL`: Shell Plastics (e.g., `SHL_Top_Cover`)
  - `BFL`: Baffle & Internal Structure (e.g., `BFL_Main`)
  - `PRT`: Acoustic Port geometry (e.g., `PRT_Reflex_Tube`)
  - `HRD`: Hardware/Fasteners (e.g., `HRD_M5_Insert`)

## 3. Body Naming
Rename bodies immediately upon creation to prevent `Body1`, `Body2`.
- `Target_Cavity`
- `Shell_Blank`
- `Rib_Pattern`
- `Port_Cutout_Tool`

## 4. Export Nomenclature (STL, STEP, IGES)
Format: `[Revision]-[Component]-[Date/Desc].[ext]`
Example: `v04-SHL_Top_Cover-For_Print.stl`

*Note: Milestone `.f3z` archives committed to Git LFS should use semantic version tags matching the repository release.*

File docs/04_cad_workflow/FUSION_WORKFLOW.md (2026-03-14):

# Fusion 360 Scan-to-CAD Workflow

This repository enforces a strict, robust workflow for reverse-engineering the DS 100F scans into a manufacturable enclosure in Fusion 360 (January 2026 or later, with Design Extension).

## 1. Top-Down Master Assembly
The main design file (`10-ENC-ASSY`) contains the master coordinate system and drives all sub-components.
- Do **not** build parts in separate files and assemble them later.
- Build sub-components in place within the master assembly.

## 2. Mesh Handling (The "Reference, Don't Convert" Rule)
Fusion's prismatic mesh-to-solid conversion (even with 2026 improvements) remains unreliable on complex, noisy 3D scan data. 
- **Rule:** Keep the imported `.stl` or `.obj` meshes as **Reference Components**.
- **Do not** attempt to convert the entire backcan or front baffle into a Solid B-Rep body.
- Hide the mesh component when not actively referencing it.

## 3. Reverse Engineering Technique
Extract parametric truth from the noisy mesh:
1. Create a Construction Plane intersecting the mesh at a critical feature (e.g., across the port center).
2. Create a Sketch on that plane.
3. Use **Create > Mesh Section Sketch** to project the mesh intersection into the sketch.
4. Use standard sketch tools (Line, Circle, Spline) to trace the section. Constrain these lines to the Master Datums or User Parameters.
5. Extrude/Revolve/Loft these bounded sketches to build the parametric solid.

*Exception:* You may use the "Organic" (T-Spline) conversion tool from the Design Extension **only** for highly localized, mathematically complex surfaces (e.g., the specific curvature of the aerodynamic port flare) if they cannot be reasonably replicated via lofts. This must be done on a pre-segmented subset of the mesh, never the whole file.

## 4. Master Datums
Before sketching, establish the key coordinate systems in the assembly root:
- **Global Origin:** Centered on the geometric center of the workstation mounting arm clamp.
- **Listening Axis:** A construction axis aiming ≈15–20° downward from horizontal.
- **Baffle Plane:** The angled mounting face for the DS 100F driver array.
- **Port Axis:** The centerline of the bass reflex tube.

## 5. Acoustic Volume Verification
The internal volume must be precisely tracked as wall thicknesses and stiffening ribs are manipulated.
1. Create a solid body representing the **Internal Cavity** (the negative space of the enclosure).
2. Measure its Volume via the `Properties` dialog.
3. Compare this to the scan-extracted baseline target.
4. The final shell is created via a Boolean Subtract/Combine: (Outer Shell Body) - (Internal Cavity Body) - (Port Solid Body).

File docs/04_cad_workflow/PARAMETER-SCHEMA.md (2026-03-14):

# Fusion 360 User Parameter Schema

To maintain parametric stability across the master assembly, avoid "magic numbers" in sketches. All critical dimensions must be driven by User Parameters.

## Naming Convention
- Use `snake_case` for all parameter names.
- Group parameters logically by prefix.

## Required Parameters

### Acoustic Variables
| Parameter | Description | Initial Value | Notes |
|---|---|---|---|
| `ac_vol_target` | Target internal acoustic volume | TBD mm³ | Sourced from CloudCompare extraction |
| `ac_vol_actual` | Measured volume of the cavity body | (Driven) | Check against target |
| `ac_port_id` | Inner diameter of reflex vent | TBD mm | |
| `ac_port_len` | Length of reflex vent centerline | TBD mm | |

### Structural / Shell Variables
| Parameter | Description | Initial Value | Notes |
|---|---|---|---|
| `sh_wall_thk` | Nominal shell wall thickness | 6.0 mm | Sourced from HIPS forming constraint |
| `sh_rib_thk` | Thickness of internal stiffening ribs | 4.0 mm | |
| `sh_rib_spacing` | Nominal pitch between ribs | 100.0 mm | |
| `sh_draft_ang` | Minimum draft angle for vacuum forming | 3 deg | Critical for mould release |

### Mounting Variables
| Parameter | Description | Initial Value | Notes |
|---|---|---|---|
| `mt_arm_dia` | Workstation monitor arm OD | TBD mm | Scan extraction required |
| `mt_bolt_dia` | Fastener clearance diameter | 5.5 mm | M5 clearance |
| `mt_boss_dia` | Boss outer diameter | 12.0 mm | |

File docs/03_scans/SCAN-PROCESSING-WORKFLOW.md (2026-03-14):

# Scan Processing Workflow: Capture to CAD

This document defines the 7-stage pipeline for translating a physical DS 100F component into actionable Fusion 360 geometry.

## Stage 1: Raw Capture
**Tool:** Creality Scan 4.7 + CR-Scan Raptor
- Use blue laser mode for 0.02 mm accuracy.
- Apply tracking markers if the part lacks geometric uniqueness.
- Execute multiple passes if necessary to overcome occlusions.
- Run internal point cloud fusion.

## Stage 2: Alignment & Segmentation
**Tool:** CloudCompare 2.14 beta
- Import the raw fused mesh.
- Use cutting planes or manual segmentation to isolate the component of interest (e.g., separating the vent from the backcan).
- Align the part to the global coordinate system (ICP or Point-Pair picking against synthetic reference planes).

## Stage 3: Volume & Datum Extraction
**Tool:** CloudCompare 2.14 beta
- Use the **Volume Computation** tool (2.5D grid-based) on a closed backcan mesh to establish the precise internal acoustic volume.
- Use **Cross-Section & Profile** to extract DXF slices of the bass reflex port.

## Stage 4: Mesh Cleanup & Reduction
**Tool:** Blender 4.1
- **Critical:** Fusion 360 performs poorly with high-poly meshes. 
- Use the Decimate modifier to reduce face count by ≥80% (target < 10,000 faces), preserving edge flow where possible.

## Stage 5: Neutral Export
**Tool:** Blender 4.1
- Export the decimated, aligned mesh as `.stl` or `.obj`.
- Retain the coordinate origin established in Stage 2.

## Stage 6: Fusion 360 Import & Referencing
**Tool:** Fusion 360 Design Extension
- Insert the decimated mesh component.
- **Do NOT** use "Convert Mesh" (prismatic conversion) on the entire body unless it is exceptionally clean.
- Ensure the reference mesh is locked in the timeline.

## Stage 7: Reverse Engineering
**Tool:** Fusion 360 Design Extension
- Create offset planes and use **Create Mesh Section Sketch** to extract true splines and circles.
- Drive parametric solid sweeps, lofts, and extrudes from these extracted sketches, never directly from the mesh faces.
- *Optional:* Use "Organic" T-Spline conversion only for highly localized subsets of geometry (e.g., complex port flares) that cannot be parametrically swept.

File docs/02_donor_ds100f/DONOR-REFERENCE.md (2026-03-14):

# Bose FreeSpace DS 100F: Donor Reference

This document serves as the master specification for the donor components. 

## Source Verification Protocol
Every property must be traced to one of the following sources:
- **Datasheet Verified**: Explicitly stated in Bose technical documentation.
- **Scan Verified**: Extracted explicitly from a Creality CR-Scan Raptor point cloud in CloudCompare or Fusion 360.
- **Measured by Teardown**: Physical measurement with calipers, scales, or REW acoustic sweep.
- **Engineering Estimate**: Pending formal verification. MUST be upgraded before final CAD freeze.

---

## 1. Transducer Specifications

| Parameter | Value | Verification Status | Notes |
|---|---|---|---|
| Low-Frequency Driver | 5.25" (133 mm) woofer | Datasheet Verified | |
| High-Frequency Driver | 2.25" (57 mm) Twiddler® | Datasheet Verified | Centrally mounted |
| Nominal Impedance | 8 Ω | Datasheet Verified | Transformer bypassed |

## 2. Acoustic Performance

| Parameter | Value | Verification Status | Notes |
|---|---|---|---|
| Frequency Response (±3 dB) | 75 Hz – 18 kHz | Datasheet Verified | |
| Frequency Range (−10 dB) | 60 Hz – 20 kHz | Datasheet Verified | |
| Nominal Dispersion | 160° conical | Datasheet Verified | Ideal for near-field off-axis |
| Sensitivity (1 W / 1 m) | 85 dB SPL | Datasheet Verified | |
| Max SPL (Continuous) | 105 dB | Datasheet Verified | |
| Power Handling (Continuous) | 100 W | Datasheet Verified | |
| Recommended High-Pass | 55 Hz (estimated) | Engineering Estimate | Datasheet is silent on exact HPF required; must verify via Bose DSP presets or REW testing |

## 3. Physical Specifications 

| Parameter | Value | Verification Status | Notes |
|---|---|---|---|
| Enclosure Type | Ported | Datasheet Verified | Explicitly listed as ported |
| Total Unit Weight | 5.9 kg (13 lbs) | Datasheet Verified | Includes transformer/backcan |
| Outer Flange Diameter | 299 mm (11.8") | Datasheet Verified | |
| Depth | 193 mm (7.6") | Datasheet Verified | |
| Mounting Hole Cutout | 267 mm (10.5") | Datasheet Verified | |

## 4. Unknowns Requiring Extraction from Scans

The following properties are **unknown** from the datasheet and must be measured:
1. **Internal Acoustic Volume**: The precise cubic volume enclosing the rear of the drivers.
2. **Bass Reflex Port Inner Diameter**: The flare and throat diameter of the port tube.
3. **Bass Reflex Port Length**: The acoustic centerline length of the port tube.
4. **Driver Mounting Pitch Circle**: The hole pattern securing the driver assembly to the baffle.
5. **Crossover Board Envelope**: The 3D bounding box for the bare PCB (with transformer removed).
6. **Transformer Mass Saving**: Exact weight of the 70V/100V transformer yielding net assembly weight.

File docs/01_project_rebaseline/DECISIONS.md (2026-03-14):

# Architectural Decision Records (ADRs)

## ADR-001: Donor Platform Rebaseline

**Date:** 2026-03-14  
**Status:** Accepted

**Context:** The initial proposal utilized the Bose DM8C. A more appropriate, compact, and available donor unit, the Bose FreeSpace DS 100F, was secured.

**Decision:** The repository is fully rebaselined to target the DS 100F. All prior DM8C specifications are discarded.

**Consequences:** 
- New baseline specifications (5.25" woofer + 2.25" Twiddler, ported, 5.9 kg total).
- Scans of the DS 100F subassemblies become the geometric ground truth.
- Port measurement and extraction is mandatory.

---

## ADR-002: Fusion 360 CAD Workflow

**Date:** 2026-03-14  
**Status:** Accepted

**Context:** The initial conceptual proposal referenced Siemens NX. The active engineering environment is now Fusion 360 with the Design Extension.

**Decision:** Fusion 360 is the authoritative CAD platform for reverse engineering and mechanical design.

**Consequences:**
- Workflows must rely on Mesh Section Sketch tracing rather than generic organic conversion.
- Fusion file naming conventions and parameter schemas are enforced.

---

## ADR-003: Strict Scan-Driven Geometry

**Date:** 2026-03-14  
**Status:** Accepted

**Context:** Prior iterations guessed at internal dimensions. Because we now have sub-millimeter Creality CR-Scan Raptor point clouds, guessing is unacceptable.

**Decision:** No geometric or acoustic dimension (volume, port length, boss location) is allowed into the CAD master model unless it is traceable to either the Bose datasheet or a direct extraction from the scan data.

**Consequences:**
- Any missing value is marked TBD and tracked via a Measurement Task GitHub Issue.
- The `GEOMETRY-REGISTER.md` and `ACOUSTIC-REGISTER.md` track the verification status of all parameters.

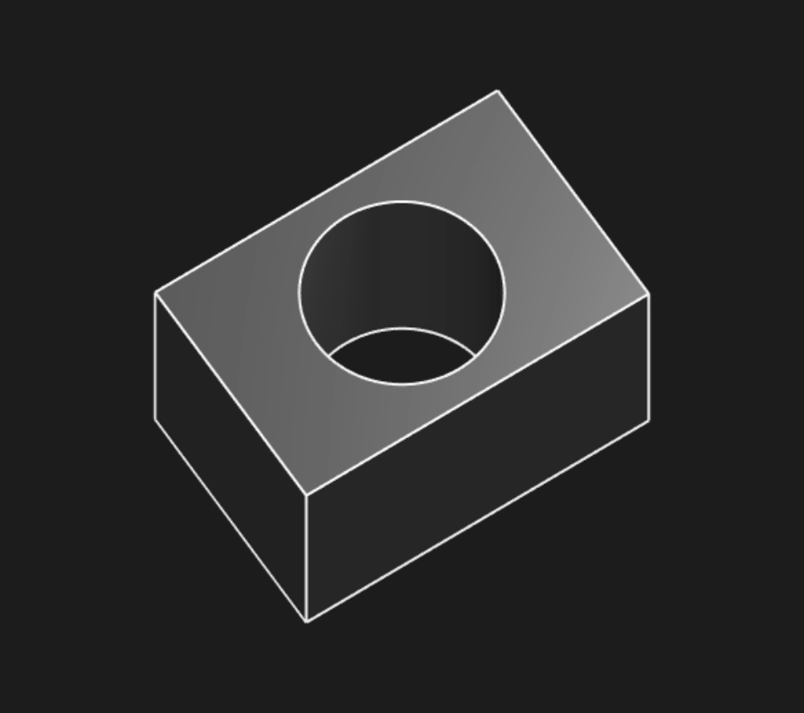
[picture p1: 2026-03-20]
thumbnail.png

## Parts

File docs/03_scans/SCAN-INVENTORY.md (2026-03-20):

# Scan Inventory

This document tracks the status of all 3D scan data captured for the DS 100F rebaseline. 

| Component | Status | Capture Tool | Alignment | Ref File | Notes |
|---|---|---|---|---|---|
| Front Panel / Base | Completed | CR-Scan Raptor | TBD | `base_with_components` (.stl/.obj/.ply) | Includes driver array. BBox: 300×150×300mm |
| Backcan | Completed | CR-Scan Raptor | TBD | `metal backcan.obj` (57MB) | Non-watertight mesh, 1.05M faces. Convex hull vol: 8.0L |
| Connector Panel | Completed | CR-Scan Raptor | TBD | `connector box` (.obj/.stl) | BBox: 156×56×139mm |
| Bass Reflex Vent | Completed | CR-Scan Raptor | TBD | `bassreflex vent pipe` (.obj/.stl) | Flared port: entry Ø40→bore Ø27→exit Ø20mm, length ~120mm |
| Workstation Arm | **Missing** | TBD | TBD | TBD | Must capture mounting zone clearance |

## Scan Analysis Results (2026-03-15)

Automated analysis performed by `trimesh` Python library. Results stored in `scan_analysis_results.json`.

### Key Findings
- **None of the meshes are watertight** — typical for raw CR-Scan Raptor captures
- The backcan mesh has significant holes, making internal volume extraction unreliable. Mesh repair recommended before CAD import.
- The vent tube shows a clear **flared bass-reflex port profile** — this is consistent with professional port design for reducing turbulent noise (chuffing)
- Simplified base assembly mesh (15MB) is available for faster loading

*All completed scans were captured in Creality Scan 4.7 using the CR-Scan Raptor in blue laser mode. Meshes were fused from point clouds internally within the Creality application.*

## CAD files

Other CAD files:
scans_repaired/base_assembly_decimated.stl
scans_repaired/base_assembly_watertight.stl
scans_repaired/base_assembly_repaired.stl
tools/backcan_poisson_d8.stl
scans_repaired/bassreflex_vent_decimated.stl
tools/backcan_poisson_d7.stl
scans_repaired/connector_box_repaired.stl
tools/backcan_nobox_poisson.stl
scans_repaired/metal_backcan_decimated.stl
tools/backcan_poisson.stl
scans_repaired/connector_box_decimated.stl
tools/backcan_clean_poisson.stl
scans_repaired/bassreflex_vent_repaired.stl
scans_repaired/bassreflex_vent_watertight.stl
scans_repaired/connector_box_watertight.stl
scans_repaired/metal_backcan_watertight.stl
scans_repaired/metal_backcan_repaired.stl

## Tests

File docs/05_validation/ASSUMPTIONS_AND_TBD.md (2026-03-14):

# Assumptions and TBD Register

Discipline in tracking knowledge state is critical for this rebaseline. Every engineering parameter exists in one of three buckets:

## 1. Verified (Ground Truth)
Parameters validated by OEM datasheet or direct measurement.
- **Donor:** Bose FreeSpace DS 100F
- **Architecture:** Ported
- **LF/HF Drivers:** 5.25" / 2.25"
- **Nominal Impedance:** 8 Ω
- **Dispersion:** 160° conical

## 2. Assumed (Working Theory - Must Verify)
Parameters assumed for planning but pending hard verification.
- The 430 × 280 mm Formech 300XQ envelope is sufficient for a single-pull upper shell.
- The 5.9 kg donor weight includes a ~1.0 kg transformer that can be discarded.
- The recommended high-pass filter is ≈55 Hz.

## 3. Unknown (TBD - Blocked)
Parameters totally unknown, requiring active measurement before CAD can proceed.
- Internal acoustic volume.
- Port tube inner diameter, length, and flare profile.
- Driver mounting pitch circle and baffle cutouts.
- Crossover PCB bounding box.
- Monitor arm mounting tube diameter and clearance.

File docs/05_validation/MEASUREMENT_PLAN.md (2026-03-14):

# Measurement Plan

This plan resolves the items in the "Unknown (TBD)" bucket.

## Phase 1: Scan Extraction (CloudCompare)
**Owner:** CAD / Validation
**Objective:** Non-destructive geometric extraction.
1. `ac_vol_target`: Isolate the backcan scan. Cap the front opening. Run Volume Computation.
2. `ac_port_id` & `ac_port_len`: Section the vent scan. Measure DXF profile.

## Phase 2: Physical Teardown Verification
**Owner:** Engineering
**Objective:** Hard validation of internal components.
1. `pcb_bounding_box`: Remeasure the crossover board with calipers.
2. `transformer_weight`: Weigh the 70V transformer to confirm mass savings.
3. `driver_pitch_dia`: Confirm bolt hole radial position on the actual driver chassis.

## Phase 3: Acoustic Baseline Validation
**Owner:** Acoustic
**Objective:** Define the target curve before enclosure design.
1. Perform a free-air or infinite baffle impedance sweep (REW / DATS) on the raw driver array to find Fs and confirm T/S parameters if simulation (VituixCAD) is desired.
2. Characterize the crossover network transfer function (if possible without destruction).

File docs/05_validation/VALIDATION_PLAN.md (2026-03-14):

# Validation Plan

How do we know the custom DS 100F enclosure works?

## 1. Structural Validation
- **Mass Check:** Total assembly must weigh ≤ 4.5 kg before mounting.
- **Modal Check:** Shell should not exhibit audible rattles or "oil-canning" when stimulated with a 40–200 Hz sweep at 90 dB.
- **Mounting Check:** Bracket must hold angle without drooping under vibration.

## 2. Acoustic Validation (REW)
- **Port Tuning:** Impedance sweep of the final enclosure must show an impedance saddle matching the original DS 100F tuning frequency (extracted during teardown).
- **Frequency Response:** Near-field (1m) measurement must achieve ±3 dB window from ~75 Hz to 18 kHz, matching the donor voicing.
- **Air Leaks:** No audible chuffing from panel seams during 50 Hz sine wave excitation at 20 W.

## 3. Manufacturing Validation
- **Draft Angle Analysis:** All vacuum-formed faces must pass a ≥ 3° draft check in Fusion 360.
- **Placing Volume:** The shell blank must fit entirely within the 430 × 280 mm Formech 300XQ envelope unless a multi-part split is defined.

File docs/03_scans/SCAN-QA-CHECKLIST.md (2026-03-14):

# Scan QA Checklist

Before exporting a mesh for CAD use in Fusion 360, it must pass the following QA criteria.

## 1. Raw Point Cloud Quality (Creality Scan)
- [ ] Captured in blue laser mode (for CR-Scan Raptor).
- [ ] No major occlusion zones or "shadows" on critical geometry (e.g., inside the port tube).
- [ ] Tracking maintained consistently; no ghosting or duplicated surfaces.

## 2. Fusion and Cleaning (CloudCompare / Blender)
- [ ] Point cloud correctly fused into a manifold mesh.
- [ ] Extraneous data (background, table, mounting putty) segmented and deleted.
- [ ] Face count reduced to ≤ 10,000 polygons (via Blender Decimate or CloudCompare Poisson Recon) to prevent Fusion 360 instability.

## 3. Alignment
- [ ] Mesh oriented to a logical coordinate system (e.g., Z-axis = driver firing axis).
- [ ] Origin point established at a meaningful geometric datum (e.g., backcan mounting flange center).

## 4. Final Export
- [ ] Exported as standard format (`.stl`, `.ply`, or `.obj`).
- [ ] Verified scale in CAD (check one known bounding dimension with calipers).

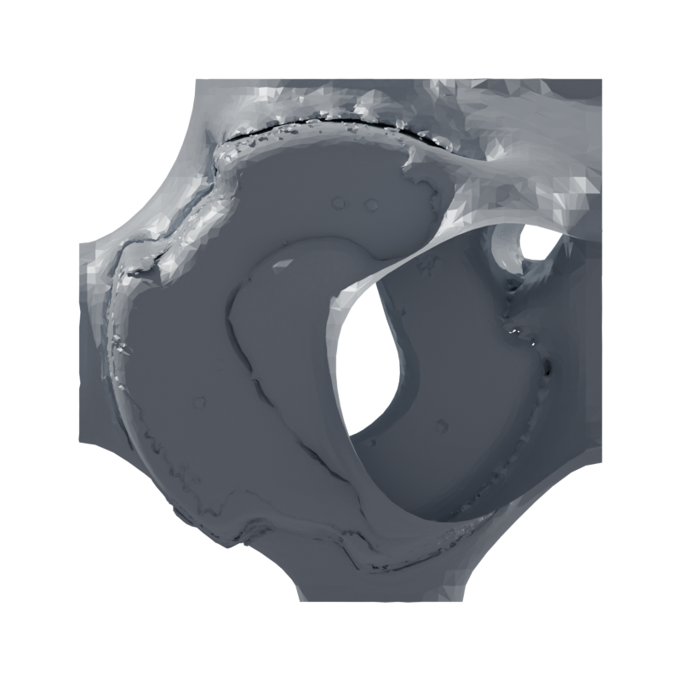
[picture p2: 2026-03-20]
renders_test/view_rear.png

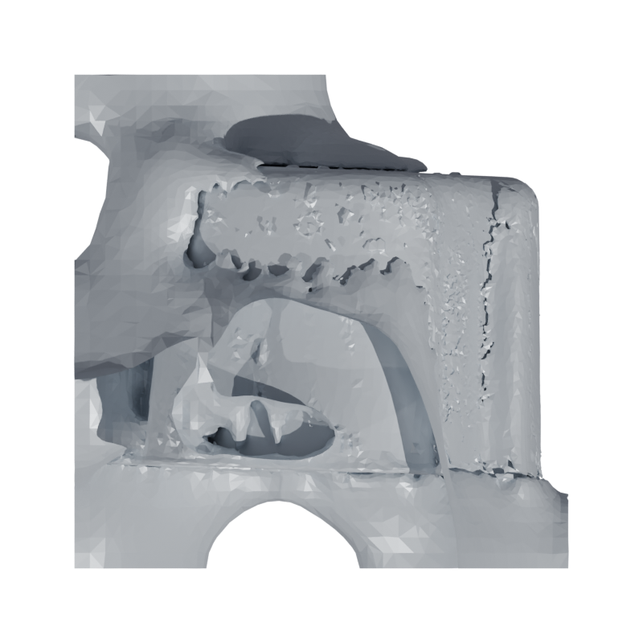
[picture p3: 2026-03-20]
renders_test/view_top.png

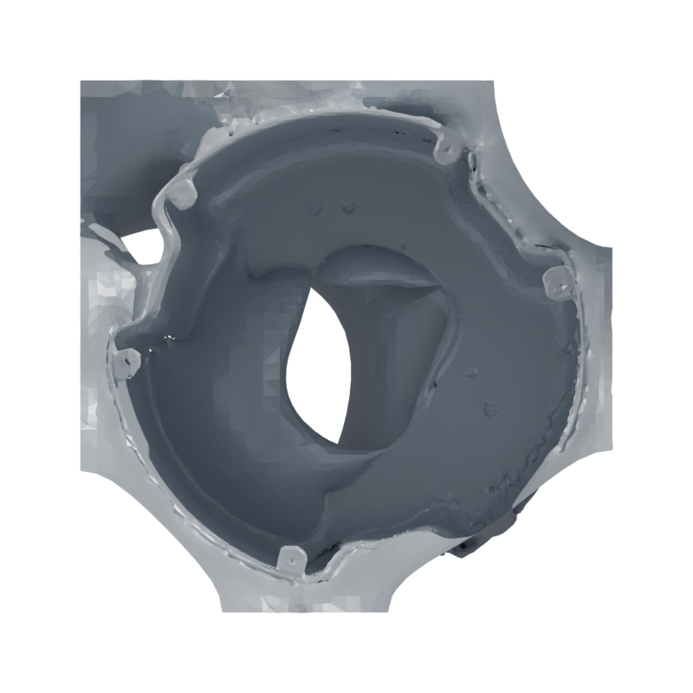
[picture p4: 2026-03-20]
renders_test/view_front.png

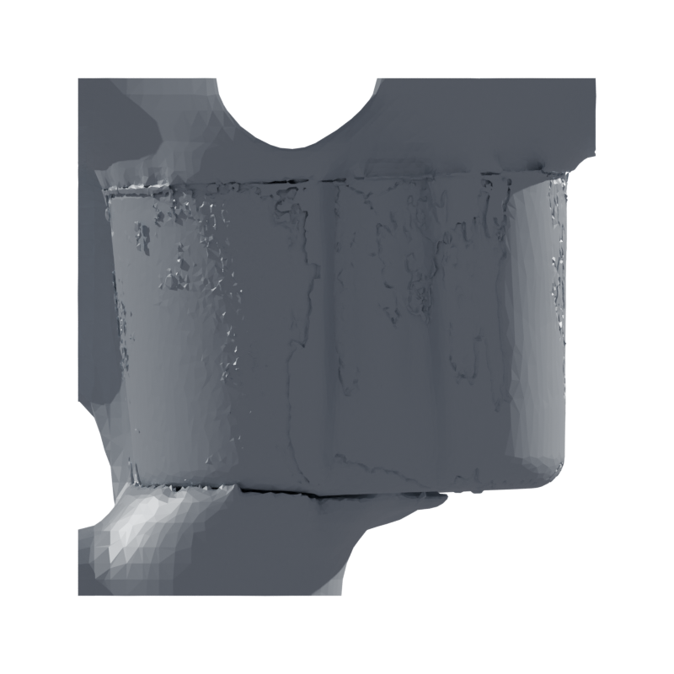
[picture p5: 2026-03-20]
renders_test/view_bottom.png

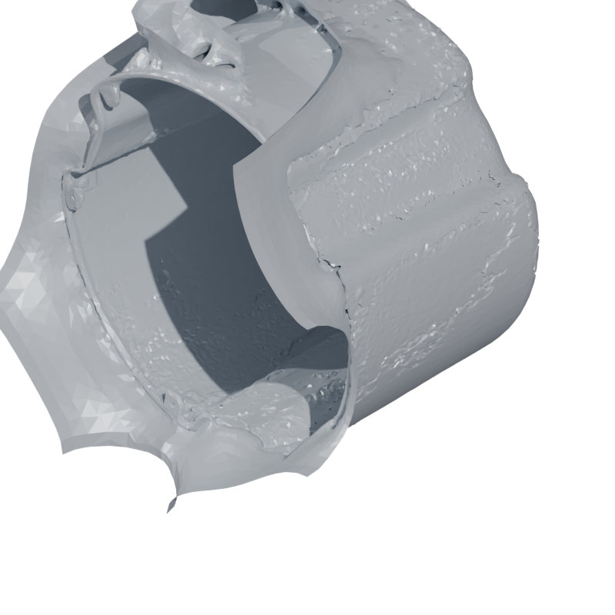
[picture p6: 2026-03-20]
renders_test/view_iso.png

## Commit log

2026-03-13 docs: Initial import of speaker enclosure design proposal
2026-03-14 docs(cad): establish Fusion 360 naming and parameter schemas
2026-03-20 feat: headless mesh render pipeline (Blender Cycles GPU)
    - mesh_render.py: Blender-based headless renderer via --background
    - 6 orthographic views (front/right/top/iso/bottom/rear)
    - Cycles GPU rendering, ~44s total for 800px resolution
    - Cross-section bisect WIP (coordinate space issue)
    - Tested on metal_backcan_decimated.stl
    [base_assembly_decimated.stl, base_assembly_repaired.stl, base_assembly_watertight.stl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]
2026-03-20 fix: cross-section bisect world-to-local coordinate transform
    The bisect operator works in object-local space but was receiving
    world-space coordinates, causing blank/incorrect cross-sections
    when the mesh origin wasn't at the world origin.
    Fix: transform plane_co and plane_no through matrix_world.inverted()
    before passing to bpy.ops.mesh.bisect.
    Verified via Blender MCP on bakcan-reduced.stl (102k verts).
2026-03-20 Volume analysis: displacement volumes verified, exploded view, Discord summary
    - Gross backcan volume: ~6.1L (hole-fill method)
    - Displacement via assembly scan: 1,582 cm³ (1.58L)
    - Displacement via sum-of-parts: 1,357 cm³ (1.36L)
    - Net air volume estimate: ~4.5L
    - Exploded view of all components in Blender
    - Poisson reconstruction documented as unsuitable for thin-walled scans
    [backcan_clean_poisson.stl, backcan_nobox_poisson.stl, backcan_poisson.stl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]
